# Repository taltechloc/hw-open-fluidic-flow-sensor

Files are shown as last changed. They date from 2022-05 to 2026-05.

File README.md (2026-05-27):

# Open-source Low Cost Wireless flow velocity sensor

## Features:

- Flow Velocity and Flow Rate Measurement of distilled water and air segmented flow
- 3D printed and low cost
- Wireless connection
- Battery powered

*Designed by: Nicky Andre Prabatama.*
*Please be kind and cite me if you use my designs:*
- Original source: https://doi.org/10.1109/BEC56180.2022.9935606

## Construction and use

Folders: 
- Documentation: **Please read the user manual under the Documentation folder first!**
- Electronics: schematics and BOM
- Firmware: Arduino source code, Android Application source code in Kotlin, and Website source code in HTML, CSS, and Javascript
- Mechanical: STL files for 3D printing. Use an FDM printer such as a [Prusa](https://www.prusa3d.com/category/3d-printers/). 

Please note that we cannot offer support or take responsibility for damage caused by using this product.

----
*This is an OSHW project*

OSHW logo

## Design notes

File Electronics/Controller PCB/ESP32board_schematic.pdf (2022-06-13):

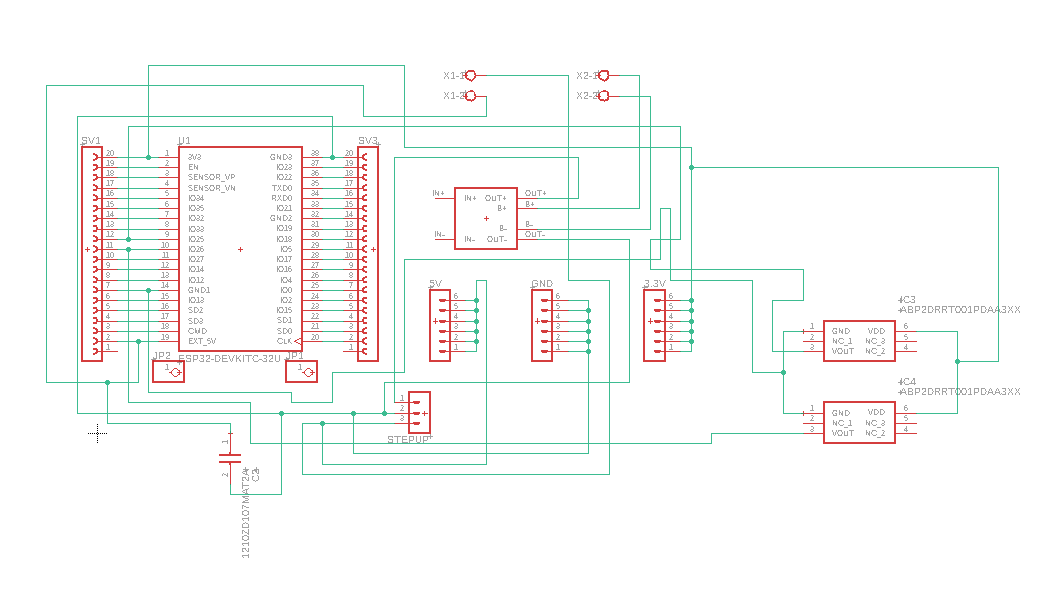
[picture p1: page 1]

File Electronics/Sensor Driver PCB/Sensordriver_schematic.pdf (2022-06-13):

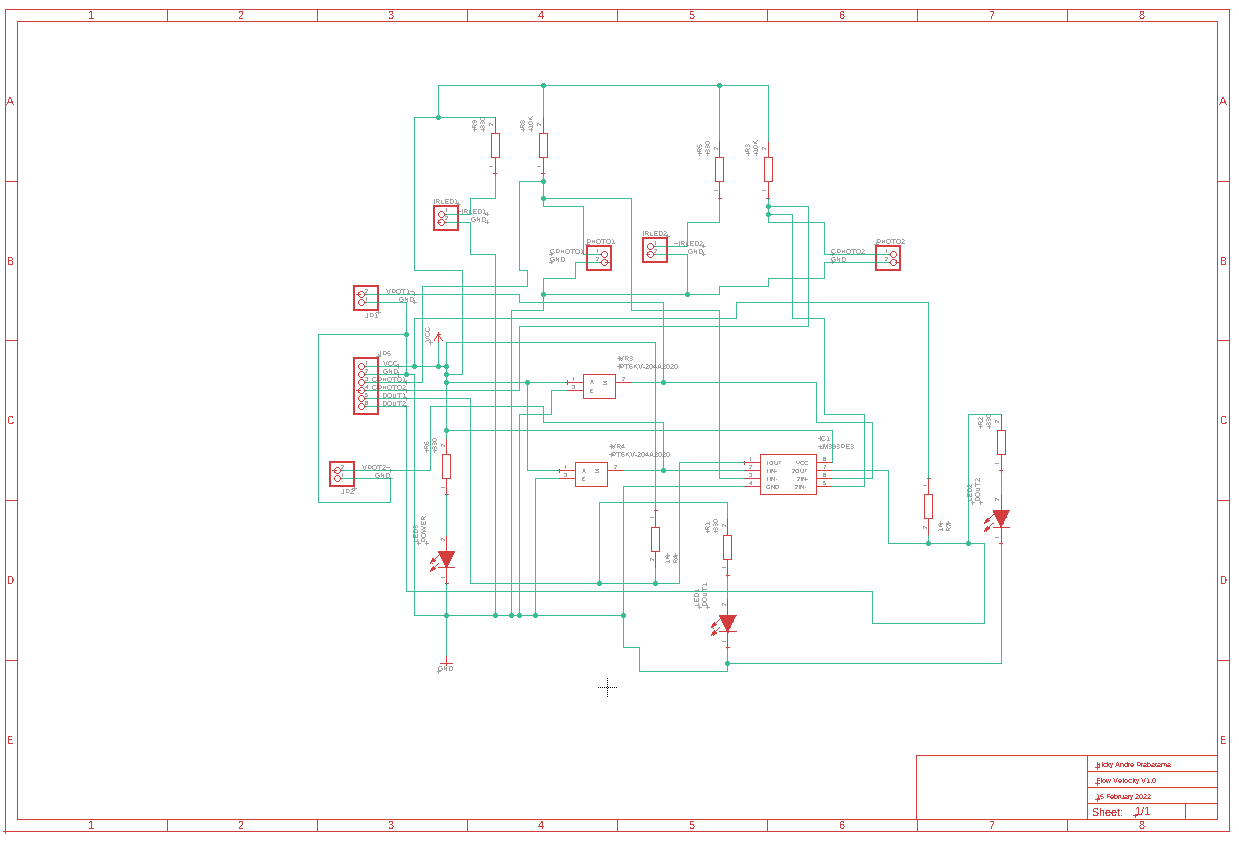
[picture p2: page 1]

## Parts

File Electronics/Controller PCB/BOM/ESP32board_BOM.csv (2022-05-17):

Qty | Value | Device | Package | Parts | Description | AVAILABILITY | DESCRIPTION | HEIGHT | MANUFACTURER_NAME | MANUFACTURER_PART_NUMBER | MF | MOUSER_PART_NUMBER | MOUSER_PRICE-STOCK | MP | MPN | OC_FARNELL | OC_NEWARK | PACKAGE | POPULARITY | PRICE | PURCHASE-URL
2 |  | FE20-1 | FE20 | SV1, SV3 | FEMALE HEADER |  |  |  |  |  |  |  |  |  |  | unknown | unknown |  | 3
1 |  | MA03-1 | MA03-1 | STEPUP | PIN HEADER |  |  |  |  |  |  |  |  |  |  | unknown | unknown |  | 48
3 |  | MA06-1 | MA06-1 | 3.3V, 5V, GND | PIN HEADER |  |  |  |  |  |  |  |  |  |  | unknown | unknown |  | 28
2 |  | PINHD-1X1 | 1X01 | JP1, JP2 | PIN HEADER |  |  |  |  |  |  |  |  |  |  |  |  |  | 64
2 |  | W237-102 | W237-102 | X1, X2 | WAGO SCREW CLAMP |  |  |  |  |  |  |  |  |  | 237-102 | unknown | 70K9898 |  | 32
1 | 1210ZD107MAT2A | 1210ZD107MAT2A | CAPC3225X279N | C2 | Multilayer Ceramic Capacitors MLCC - SMD/SMT 10V 100uF 75 1210 20% HIGH CV |  | Multilayer Ceramic Capacitors MLCC - SMD/SMT 10V 100uF 75 1210 20% HIGH CV | 2.79mm | AVX | 1210ZD107MAT2A |  | 581-1210ZD107MAT2A | https://www.mouser.co.uk/ProductDetail/AVX/1210ZD107MAT2A?qs=hpwIUhX6lWxhOZjeKgHORg%3D%3D
2 | ABP2DRRT001PDAA3XX | ABP2DRRT001PDAA3XX | ABP2DRRT001PDAA3XX | IC3, IC4 | Board Mount Pressure Sensors BASIC PRESSURE,DIP |  | Board Mount Pressure Sensors BASIC PRESSURE,DIP | 6.82mm | Honeywell | ABP2DRRT001PDAA3XX |  | 785-P2DRRT001PDAA3XX | https://www.mouser.co.uk/ProductDetail/Honeywell/ABP2DRRT001PDAA3XX?qs=ljCeji4nMDmtNzy%252B%2Fo3xmg%3D%3D
1 | ESP32-DEVKITC-32U | ESP32-DEVKITC-32U | MODULE_ESP32-DEVKITC-32U | U1 | ESP32-DEVKITC Check availability | In Stock | ESP32-WROOM-32UE series Transceiver | 802.11 b/g/n (Wi-Fi, WiFi, WLAN), Bluetooth® Smart Ready 4.x Dual Mode Evaluation Board |  |  |  | Espressif Systems |  |  | ESP32-DEVKITC-32U |  |  |  | None |  | None
1 | TP4056-MODULE | TP4056-MODULE | TP4056-LITHIUM-PROTECTED-MODULE | U$2

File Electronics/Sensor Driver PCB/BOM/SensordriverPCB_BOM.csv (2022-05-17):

Qty | Value | Device | Package | Parts | Description | DESCRIPTION | HEIGHT | MANUFACTURER_NAME | MANUFACTURER_PART_NUMBER | MOUSER_PART_NUMBER | MOUSER_PRICE-STOCK | POPULARITY
6 |  | PINHD-1X2 | 1X02 | IRLED1, IRLED2, JP1, JP2, PHOTO1, PHOTO2 | PIN HEADER |  |  |  |  |  |  | 98
1 |  | PINHD-1X6 | 1X06 | JP5 | PIN HEADER |  |  |  |  |  |  | 79
2 | 10K | CRCW080510K0FKEAC | RESC2012X60N | R3, R8 | Thick Film Resistors - SMD 1/8Watt 10Kohms 1% Commercial Use | Thick Film Resistors - SMD 1/8Watt 10Kohms 1% Commercial Use | 0.6mm | Vishay | CRCW080510K0FKEAC | 71-CRCW080510K0FKEAC | https://www.mouser.co.uk/ProductDetail/Vishay-Dale/CRCW080510K0FKEAC?qs=E3Y5ESvWgWORadmUijPtxQ%3D%3D
2 | 1K | CRS0805-FX-1001ELF | RESC2012X60N | R4, R7 | 1k 0805 Thick Film Anti Surge Fixed Resistor +/-1% 0.25W - CRS0805-FX-1001ELF | 1k 0805 Thick Film Anti Surge Fixed Resistor +/-1% 0.25W - CRS0805-FX-1001ELF | 0.6mm | Bourns | CRS0805-FX-1001ELF | 652-CRS0805FX1001ELF | https://www.mouser.co.uk/ProductDetail/Bourns/CRS0805-FX-1001ELF?qs=3ZbGupGMFUdZykYWZvWIOw%3D%3D
5 | 330 | CR0805-JW-330ELF | RESC2012X60N | R1, R2, R5, R6, R9 | BOURNS - CR0805-JW-330ELF - RES, THICK FILM, 33R, 5%, 0.125W, 0805 | BOURNS - CR0805-JW-330ELF - RES, THICK FILM, 33R, 5%, 0.125W, 0805 | 0.6mm | Bourns | CR0805-JW-330ELF | 652-CR0805JW-330ELF | https://www.mouser.com/Search/Refine.aspx?Keyword=652-CR0805JW-330ELF
1 | DOUT1 | 150060RS75000 | LEDC1608X80N | LED1 | WURTH ELEKTRONIK - 150060RS75000 - LED, 0603, RED, 250MCD, 625NM | WURTH ELEKTRONIK - 150060RS75000 - LED, 0603, RED, 250MCD, 625NM | 0.8mm | Wurth Elektronik | 150060RS75000 | 710-150060RS75000 | https://www.mouser.co.uk/ProductDetail/Wurth-Elektronik/150060RS75000?qs=LlUlMxKIyB3QnmZ3fw%2FVCA%3D%3D
1 | DOUT2 | 150060RS75000 | LEDC1608X80N | LED2 | WURTH ELEKTRONIK - 150060RS75000 - LED, 0603, RED, 250MCD, 625NM | WURTH ELEKTRONIK - 150060RS75000 - LED, 0603, RED, 250MCD, 625NM | 0.8mm | Wurth Elektronik | 150060RS75000 | 710-150060RS75000 | https://www.mouser.co.uk/ProductDetail/Wurth-Elektronik/150060RS75000?qs=LlUlMxKIyB3QnmZ3fw%2FVCA%3D%3D
1 | LM393PE3 | LM393PE3 | DIP794W53P254L959H508Q8N | IC1 | Dual differential comparator, commercial grade | Dual differential comparator, commercial grade | 5.08mm | Texas Instruments | LM393PE3 | 595-LM393PE3 | https://www.mouser.co.uk/ProductDetail/Texas-Instruments/LM393PE3?qs=EuM%2FBx4ov4RUODAufCAVgA%3D%3D
1 | POWER | 150060RS75000 | LEDC1608X80N | LED3 | WURTH ELEKTRONIK - 150060RS75000 - LED, 0603, RED, 250MCD, 625NM | WURTH ELEKTRONIK - 150060RS75000 - LED, 0603, RED, 250MCD, 625NM | 0.8mm | Wurth Elektronik | 150060RS75000 | 710-150060RS75000 | https://www.mouser.co.uk/ProductDetail/Wurth-Elektronik/150060RS75000?qs=LlUlMxKIyB3QnmZ3fw%2FVCA%3D%3D
2 | PT6KV-204A2020 | PT6KV-204A2020 | PT6MV103A2020E | VR3, VR4 | 6MM TRIMMER POTENTIOMETER THT | 6MM TRIMMER POTENTIOMETER THT | 4mm | PIHER | PT6KV-204A2020 | 531-PT6KV-204A2020 | https://www.mouser.co.uk/ProductDetail/Amphenol-Piher/PT6KV-204A2020?qs=DPoM0jnrROXB9pG8c6GveA%3D%3D

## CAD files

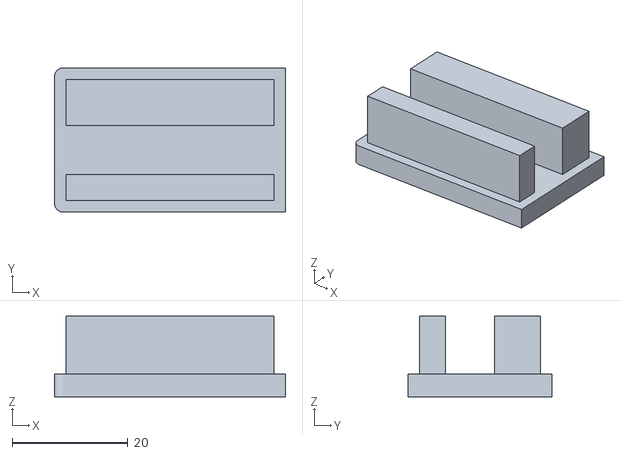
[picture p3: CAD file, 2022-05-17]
Mechanical/sensorstand.stl
40.0 x 25.0 x 14.0

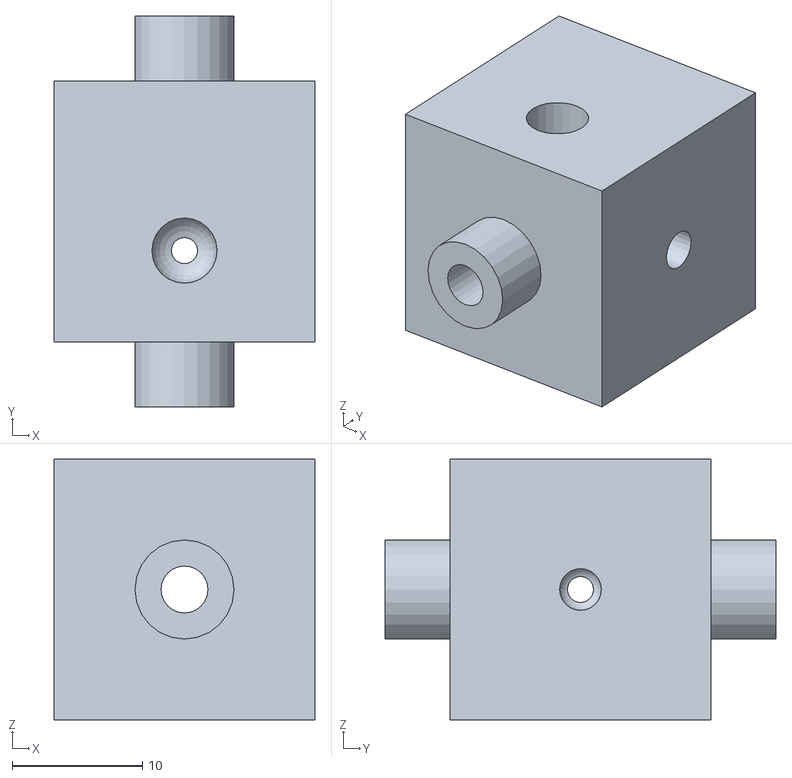
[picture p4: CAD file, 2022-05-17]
Mechanical/3mmsensorbox-1.stl
20.0 x 30.0 x 20.0

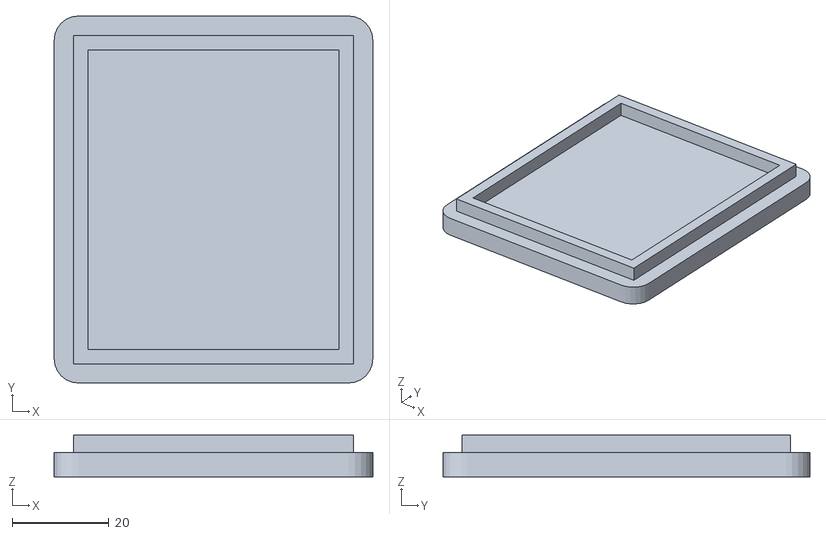
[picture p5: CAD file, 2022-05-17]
Mechanical/sensorboardboxcover.stl
66.0 x 76.0 x 8.61

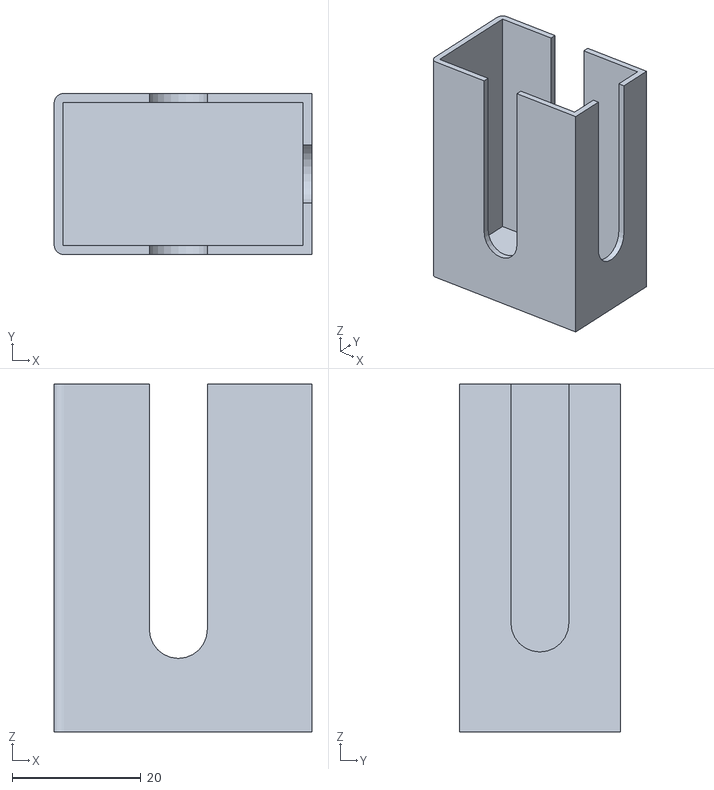
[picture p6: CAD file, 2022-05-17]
Mechanical/fix cover.stl
40.0 x 25.0 x 54.0

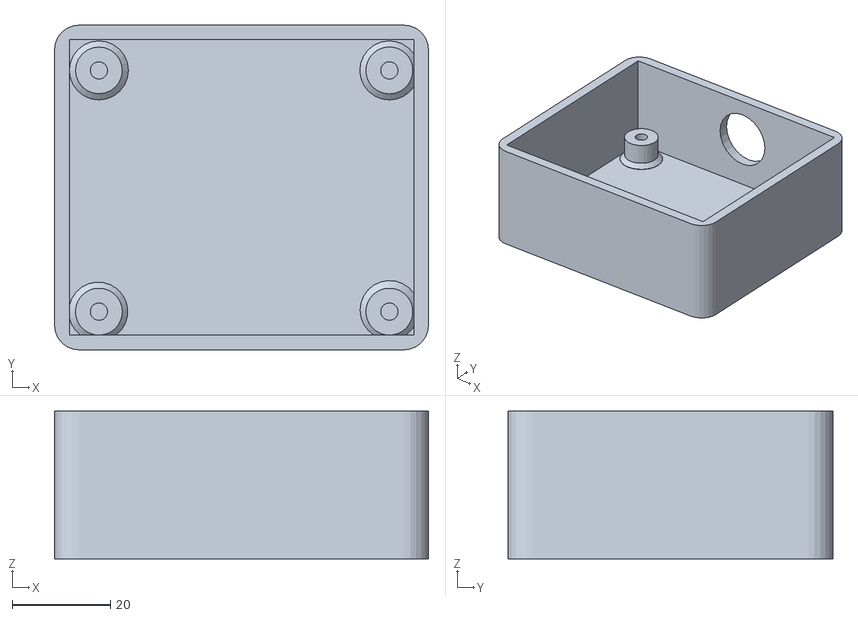
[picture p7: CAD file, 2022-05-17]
Mechanical/sensorboardboxnew.stl
76.0 x 66.0 x 30.0

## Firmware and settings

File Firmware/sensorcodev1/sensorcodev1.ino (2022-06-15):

#include <esp_now.h>
#include <esp_wifi.h>
#include <WiFi.h>
#include <Ewma.h>

// REPLACE WITH YOUR RECEIVER MAC Address
uint8_t broadcastAddress[] = {0xA4, 0xE5, 0x7C, 0xE0, 0xF6, 0x84};

extern volatile unsigned long timer0_millis;

// Insert your SSID
constexpr char WIFI_SSID[] = "TendaRozsa";

int32_t getWiFiChannel(const char *ssid) {
  if (int32_t n = WiFi.scanNetworks()) {
      for (uint8_t i=0; i<n; i++) {
          if (!strcmp(ssid, WiFi.SSID(i).c_str())) {
              return WiFi.channel(i);
          }
      }
  }
  return 0;
}

const int APin1 = 39;// Analog pin flow sensor1
const int APin2 = 34;// Analog pin flow sensor2

int ADCValue1;// do not change
int ADCValue2;// do not change
float voltage1 =0;// Voltage value from sensor1
float voltage2 =0;// Voltage value from sensor2
unsigned long timeone = 0;
unsigned long timetwo = 0;
const int threshold = 1.00;
float Deltat = 0;
float Velocity = 0;
float vsecond = 0;
float flowrate = 0;

//Ewma adcFilter1(0.1);   // Less smoothing - faster to detect changes, but more prone to noise
Ewma adcFilter2(0.01);  // More smoothing - less prone to noise, but slower to detect changes

// Structure example to send data
// Must match the receiver structure
typedef struct struct_message {
  char a[32];
  float b;
  float c;
  float d;
} struct_message;

// Create a struct_message called myData
struct_message myData;

esp_now_peer_info_t peerInfo;

// callback when data is sent
void OnDataSent(const uint8_t *mac_addr, esp_now_send_status_t status) {
  Serial.print("\r\nLast Packet Send Status:\t");
  Serial.println(status == ESP_NOW_SEND_SUCCESS ? "Delivery Success" : "Delivery Fail");
}

void setup() {
  // initialize serial communication at 115200 bits per second:
  Serial.begin(115200);

  WiFi.mode(WIFI_STA);

  int32_t channel = getWiFiChannel(WIFI_SSID);

  WiFi.printDiag(Serial); // Uncomment to verify channel number before
  esp_wifi_set_promiscuous(true);
  esp_wifi_set_channel(channel, WIFI_SECOND_CHAN_NONE);
  esp_wifi_set_promiscuous(false);
  WiFi.printDiag(Serial); // Uncomment to verify channel number before

    // Init ESP-NOW
  if (esp_now_init() != ESP_OK) {
    Serial.println("Error initializing ESP-NOW");
    return;
  }

  // Once ESPNow is successfully Init, we will register for Send CB to
  // get the status of Trasnmitted packet
  esp_now_register_send_cb(OnDataSent);
  
  // Register peer
  memcpy(peerInfo.peer_addr, broadcastAddress, 6);
  peerInfo.channel = 0;  
  peerInfo.encrypt = false;
  
  // Add peer        
  if (esp_now_add_peer(&peerInfo) != ESP_OK){
    Serial.println("Failed to add peer");
    return;
  }
}


void loop() {
  // read the input on analog pin potPin:
  ADCValue1 = analogRead(APin1);
  voltage1 = (3.3/4095.0) * ADCValue1;
  ADCValue2 = analogRead(APin2);
  voltage2 = (3.3/4095.0) * ADCValue2;

  if(voltage2>=threshold){
    Deltat = 0;
    //vsecond = 0;
    //flowrate = 0;
    timeone=millis();
    }

    if(voltage1>=threshold){
      //Deltat = 0;
      timetwo=millis();
      Deltat = timetwo - timeone;
      if(Deltat != 0){
      Velocity = 3.0/Deltat;
      vsecond = Velocity * 10.0; 
      flowrate = 3.14 * 0.5 * 0.5 * vsecond;
      }
      }

  
  //float average = adcFilter1.filter(raw);
  float average = adcFilter2.filter(flowrate);
  // send it to the computer as ASCII digits
  Serial.println(average);
  delay(1);        // delay in between reads for stability

  // Set values to send
  strcpy(myData.a, "FLOW SENSOR DATA");
  myData.b = vsecond;
  myData.c = average;
  myData.d = Deltat;

  // Send message via ESP-NOW
  esp_err_t result = esp_now_send(broadcastAddress, (uint8_t *) &myData, sizeof(myData));
  if (result == ESP_OK) {
    Serial.println("Sent with success");
  }
  else {
    Serial.println("Error sending the data");
  }
  
  
  

  
  Serial.print("ADCValue1:");
  Serial.print(ADCValue1);
   
  Serial.print(" Voltage1:");
  Serial.print(voltage1);
  Serial.println("V"); 
  
  Serial.print("ADCValue2:");
  Serial.print(ADCValue2);
   
  Serial.print(" Voltage2:");
  Serial.print(voltage2);
  Serial.println("V");   
  Serial.println(Deltat);
  Serial.println(vsecond);
  Serial.println(flowrate);
  Serial.println(average);
  delay(18); // delay in between reads for stability
}

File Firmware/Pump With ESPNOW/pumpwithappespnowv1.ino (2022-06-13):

// Import required libraries
#ifdef ESP32
  #include <ArduinoJson.h>
  #include <FirebaseESP32.h>
  #include <esp_now.h>
  #include <WiFi.h>
  #include <WiFiUdp.h>
  #include "time.h"
#endif

// Replace with your network credentials (STATION)
const char* ssid = "TendaRozsa"; // Set your WiFi name here
const char* password = "Rozsa2020"; // Set your WiFi password here

// Set your firebase parameters here .
#define FIREBASE_HOST "flowiot-default-rtdb.firebaseio.com"
#define FIREBASE_AUTH "iPj4dcRWiuh0nlZ3al0kfLhldYtnJfZdmfgNIePG"

FirebaseData firebaseData;
FirebaseJson json;

//void printResult (FirebaseData &data);
#include "PumpI2C.h"
uint8_t ShapeByte=0; // sine
uint8_t WaveByte=0; // full wave
uint8_t DampByte=0; // disabled
uint8_t ShapeByte2=0;
uint8_t WaveByte2=0;
uint8_t DampByte2=0;
uint8_t Pump1Address =0x78;
uint8_t Pump2Address =0x7B;
#define DEBUG true
#define LED               16
#define I2C_SDA 2
#define I2C_SCL 4

//Pump1 parameters
int VoltagePeak1=255;
int pumpfreq1 = 50;
int settime1=60;
int pumpState1 = 0;
bool mrunning1 = true;

//Pump 2 parameters
int VoltagePeak2=255;
int pumpfreq2 = 50;
int settime2=60;
int pumpState2 = 0;
bool mrunning2 = true;

float average = 0;
float velocity = 0;

const char* ntpServer = "de.pool.ntp.org";
const long  gmtOffset_sec = 3600;
const int   daylightOffset_sec = 3600;

// Structure example to receive data
// Must match the sender structure
typedef struct struct_message {
    char a[32];
    float b;
    float c;
    float d;
} struct_message;

// Create a struct_message called myData
struct_message myData;

// callback function that will be executed when data is received
void OnDataRecv(const uint8_t * mac, const uint8_t *incomingData, int len) {
  memcpy(&myData, incomingData, sizeof(myData));
  Serial.print("Bytes received: ");
  Serial.println(len);
  Serial.print("Char: ");
  Serial.println(myData.a);
  Serial.print("Velocity: ");
  Serial.println(myData.b);
  Serial.print("Flowrate: ");
  Serial.println(myData.c);
  Serial.print("Deltat: ");
  Serial.println(myData.d);
  Serial.println();
}


void setup() {

    // it is a good practice to make sure your code sets wifi mode how you want it.

    // put your setup code here, to run once:
    Serial.begin(115200);
    
    //WiFiManager, Local intialization. Once its business is done, there is no need to keep it around
   WiFi.mode(WIFI_MODE_APSTA);
  
  // Set device as a Wi-Fi Station
  WiFi.begin(ssid, password);
  while (WiFi.status() != WL_CONNECTED) {
    delay(1000);
    Serial.println("Setting as a Wi-Fi Station..");
  }
  Serial.print("Station IP Address: ");
  Serial.println(WiFi.localIP());
  Serial.print("Wi-Fi Channel: ");
  Serial.println(WiFi.channel());

  // Init ESP-NOW
  if (esp_now_init() != ESP_OK) {
    Serial.println("Error initializing ESP-NOW");
    return;
  }

  //init and get the time
  configTime(gmtOffset_sec, daylightOffset_sec, ntpServer);
  
  Firebase.begin(FIREBASE_HOST, FIREBASE_AUTH);

  Firebase.setInt(firebaseData, "pump1", 0);                                          //send initial string of led status
Firebase.setInt(firebaseData, "voltage1", 0);                                          //send initial string of led status
Firebase.setInt(firebaseData, "frequency1", 0);                                          //send initial string of led status
Firebase.setInt(firebaseData, "damping1", 0);                                          //send initial string of led status
Firebase.setInt(firebaseData, "wave1", 0);                                          //send initial string of led status
Firebase.setInt(firebaseData, "shape1", 0);                                          //send initial string of led status
Firebase.setInt(firebaseData, "pump2", 0);                                          //send initial string of led status
Firebase.setInt(firebaseData, "voltage2", 0);                                          //send initial string of led status
Firebase.setInt(firebaseData, "frequency2", 0);                                          //send initial string of led status
Firebase.setInt(firebaseData, "damping2", 0);                                          //send initial string of led status
Firebase.setInt(firebaseData, "wave2", 0);                                          //send initial string of led status
Firebase.setInt(firebaseData, "shape2", 0);                                          //send initial string of led status
Firebase.setString(firebaseData, "time", "00:00:00");                                          //send initial string of led status
Firebase.setString(firebaseData, "ratestring", "0.0");                                          //send initial string of led status
Firebase.setString(firebaseData, "velocitystring", "0.0");                                          //send initial string of led status
Wire.begin(I2C_SDA, I2C_SCL);
  Driver_setup(Pump1Address);
  Driver_setup(Pump2Address);
}





void loop() {

//pump1

if (Firebase.getInt(firebaseData, "/pump1")){
    if (firebaseData.dataType() == "int"){
      pumpState1 = firebaseData.intData();
      if (pumpState1 == 1){
        Serial.println("PUMP 1 ON");
        driver_start(Pump1Address);
      }
      else if (pumpState1 == 0){
        Serial.println("PUMP 1 OFF");
        driver_stop(Pump1Address);
      }
    }
  }

  if (Firebase.getInt(firebaseData, "/voltage1")){
    if (firebaseData.dataType() == "int"){
      VoltagePeak1=firebaseData.intData(); 
        driver_setvoltage(VoltagePeak1, Pump1Address);  
        Serial.println("PUMP 1 Voltage change");
    }
  }

  if (Firebase.getInt(firebaseData, "/frequency1")){
    if (firebaseData.dataType() == "int"){
      pumpfreq1=firebaseData.intData(); 
      driver_setfrequency(pumpfreq1, Pump1Address);
     Serial.println("PUMP 1 Frequency change");
    }
  }

  if (Firebase.getInt(firebaseData, "/damping1")){
    if (firebaseData.dataType() == "int"){
        DampByte=firebaseData.intData();
      Serial.println("PUMP 1 damping change");
        driver_shape(ShapeByte,WaveByte,DampByte, Pump1Address);   
    }
  }

if (Firebase.getInt(firebaseData, "/wave1")){
    if (firebaseData.dataType() == "int"){
        WaveByte=firebaseData.intData();
      Serial.println("PUMP 1 damping change");
        driver_shape(ShapeByte,WaveByte,DampByte, Pump1Address);   
    }
  }
if (Firebase.getInt(firebaseData, "/shape1")){
    if (firebaseData.dataType() == "int"){
       ShapeByte=firebaseData.intData();
      Serial.println("PUMP 1 shape change");
        driver_shape(ShapeByte,WaveByte,DampByte, Pump1Address);  
    }
  }
//end pump1
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

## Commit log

2022-05-17 Mechanical uploaded
    [3mmsensorbox-1.stl, fix cover.stl, sensorboardboxcover.stl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]
2022-05-17 Electronics uploaded
    [ESP32board_BOM.csv, SensordriverPCB_BOM.csv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]
